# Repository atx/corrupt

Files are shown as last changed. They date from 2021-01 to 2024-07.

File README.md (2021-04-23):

# corrupt
A 65% keyboard with a somewhat non-standard layout. Inspired by the KBT Pure Pro.

corrupt

### Specs

 * Standard GH60-style case support
 * MX-style switches
 * 2U left shift (bottom row shifted by 0.25U to the left)
 * Standard 6.25U spacebar
 * USB-C (wired-only)
 * [zmk port](https://github.com/atx/zmk/tree/corrupt)
 * Compatible FR4 plate included in the repository
 * Under-the-spacebar WE-SKEDD debugging port
 * STM32F405 MCU (total overkill)
 * Both the key plate and the PCB can be manufactured by JLC, most components are available for PCBA

### Layout



### Debugging connector

skedd

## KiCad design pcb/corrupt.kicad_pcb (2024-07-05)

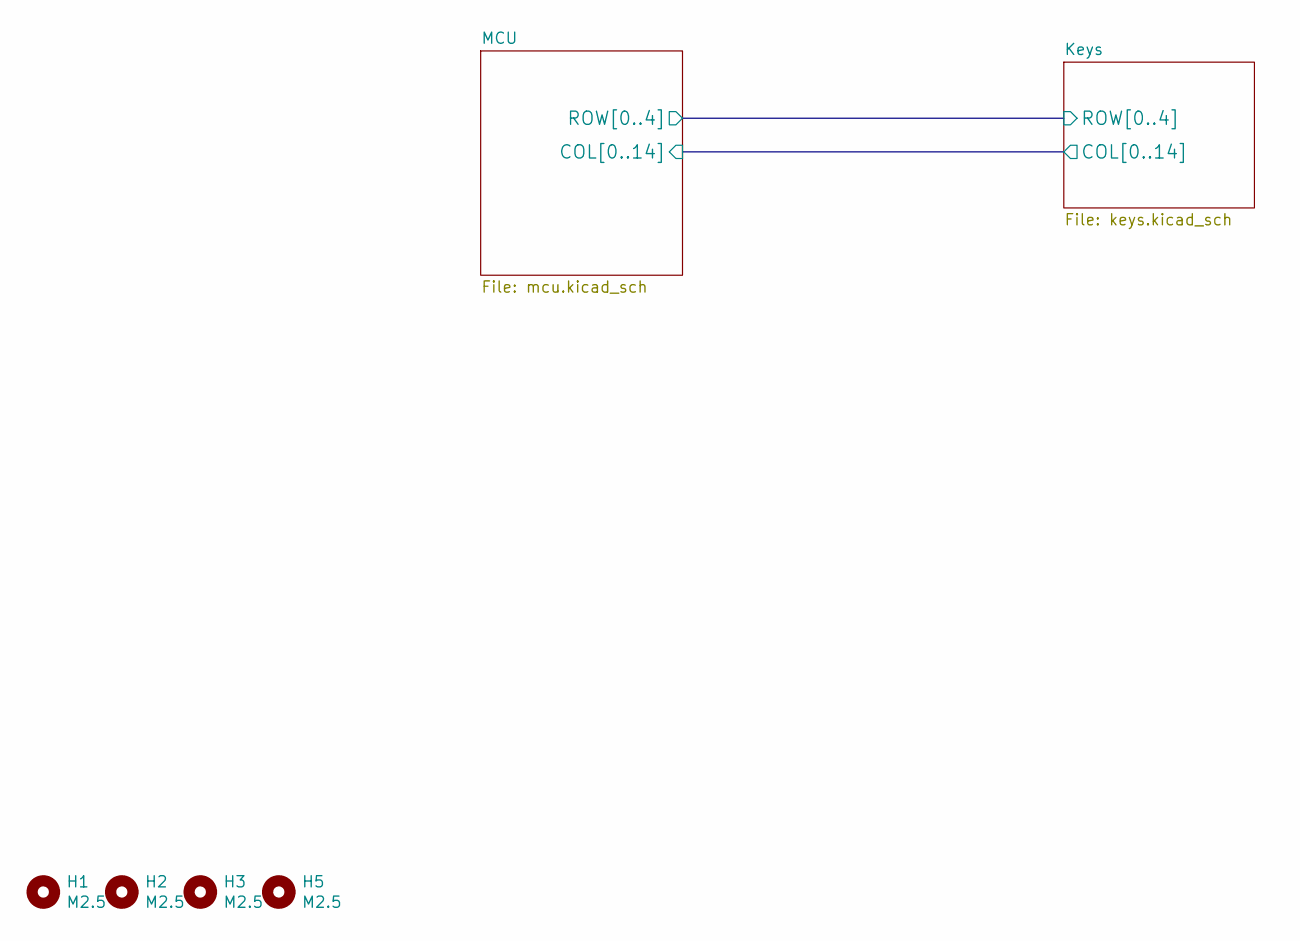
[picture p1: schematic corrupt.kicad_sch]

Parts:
H1, H2, H3, H5: M2.5; MountingHole_2.7mm_M2.5_Pad

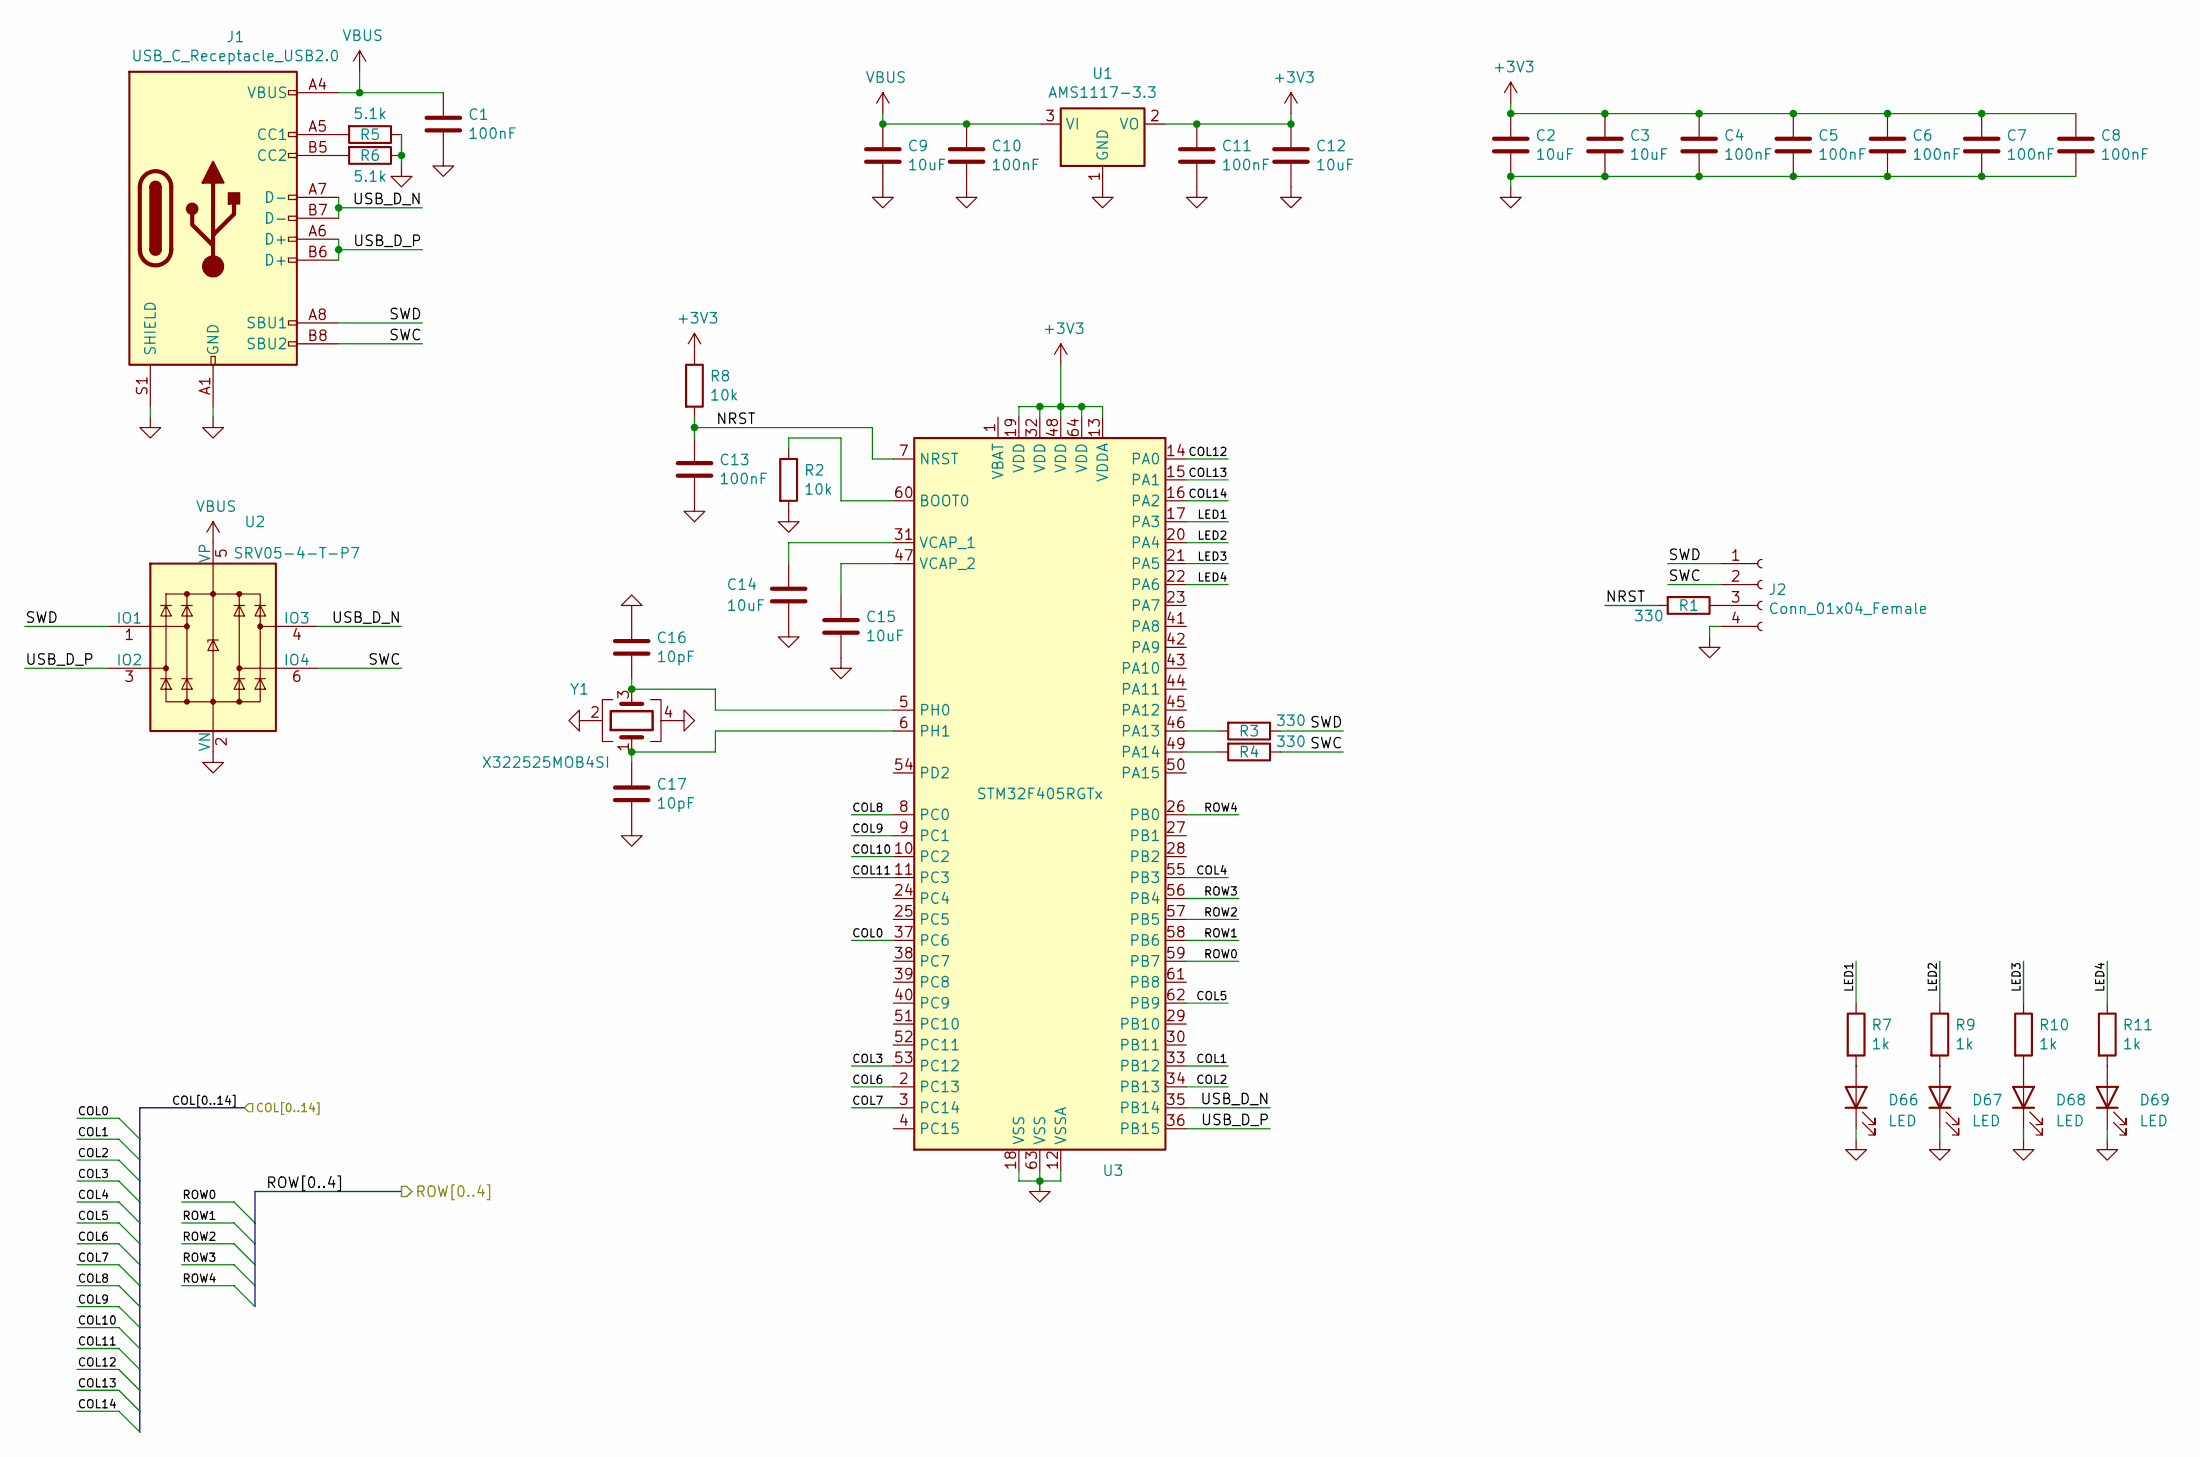
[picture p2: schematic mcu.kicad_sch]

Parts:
C1, C4, C5, C6, C7, C8, C10, C11, C13: 100nF; C_0402_1005Metric; LCSC C1525
C2, C3, C9, C12, C14, C15: 10uF; C_0603_1608Metric; LCSC C19702
C16, C17: 10pF; C_0402_1005Metric; LCSC C32949
D66, D67, D68, D69: LED; LED_0603_1608Metric
J1: USB_C_Receptacle_USB2.0; USB_C_Receptacle_Palconn_UTC16-G
J2: Conn_01x04_Female; WR-WST-4P-DBG
R1, R3, R4: 330; R_0402_1005Metric; LCSC C25104
R2, R8: 10k; R_0402_1005Metric; LCSC C25744
R5, R6: 5.1k; R_0402_1005Metric; LCSC C25905
R7, R9, R10, R11: 1k; R_0402_1005Metric; LCSC C11702
U1: AMS1117-3.3; SOT-223-3_TabPin2; LCSC C6186
U2: SRV05-4-T-P7; SOT-23-6; LCSC C7420376
U3: STM32F405RGTx; LQFP-64_10x10mm_P0.5mm; LCSC C15742
Y1: X322525MOB4SI; Crystal_SMD_3225-4Pin_3.2x2.5mm; LCSC C9006

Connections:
+3V3: C2.1, C3.1, C4.1, C5.1, C6.1, C7.1, C8.1, C11.1, C12.1, R8.1, U1.2 (VO), U3.13 (VDDA), U3.19 (VDD), U3.32 (VDD), U3.48 (VDD), U3.64 (VDD)
/Keys/COL0: U3.37 (PC6); also elsewhere on the board
/Keys/COL1: U3.33 (PB12); also elsewhere on the board
/Keys/COL2: U3.34 (PB13); also elsewhere on the board
/Keys/COL3: U3.53 (PC12); also elsewhere on the board
/Keys/COL4: U3.55 (PB3); also elsewhere on the board
/Keys/COL5: U3.62 (PB9); also elsewhere on the board
/Keys/COL6: U3.2 (PC13); also elsewhere on the board
/Keys/COL7: U3.3 (PC14); also elsewhere on the board
/Keys/COL8: U3.8 (PC0); also elsewhere on the board
/Keys/COL9: U3.9 (PC1); also elsewhere on the board
/Keys/COL10: U3.10 (PC2); also elsewhere on the board
/Keys/COL11: U3.11 (PC3); also elsewhere on the board
/Keys/COL12: U3.14 (PA0); also elsewhere on the board
/Keys/COL13: U3.15 (PA1); also elsewhere on the board
/Keys/COL14: U3.16 (PA2); also elsewhere on the board
/Keys/ROW0: U3.59 (PB7); also elsewhere on the board
/Keys/ROW1: U3.58 (PB6); also elsewhere on the board
/Keys/ROW2: U3.57 (PB5); also elsewhere on the board
/Keys/ROW3: U3.56 (PB4); also elsewhere on the board
/Keys/ROW4: U3.26 (PB0); also elsewhere on the board
/MCU/LED1: R7.1, U3.17 (PA3)
/MCU/LED2: R9.1, U3.20 (PA4)
/MCU/LED3: R10.1, U3.21 (PA5)
/MCU/LED4: R11.1, U3.22 (PA6)
/MCU/NRST: C13.1, R1.2, R8.2, U3.7 (NRST)
/MCU/SWC: J1.B8 (SBU2), J2.2, R4.1, U2.6 (IO4)
/MCU/SWD: J1.A8 (SBU1), J2.1, R3.1, U2.1 (IO1)
/MCU/USB_D_N: J1.A7 (D-), J1.B7 (D-), U2.4 (IO3), U3.35 (PB14)
/MCU/USB_D_P: J1.A6 (D+), J1.B6 (D+), U2.3 (IO2), U3.36 (PB15)
GND: C1.2, C2.2, C3.2, C4.2, C5.2, C6.2, C7.2, C8.2, C9.2, C10.2, C11.2, C12.2, C13.2, C14.2, C15.2, C16.1, C17.2, D66.1 (K), D67.1 (K), D68.1 (K), D69.1 (K), J1.A1 (GND), J1.A12 (GND), J1.B1 (GND), J1.B12 (GND), J1.S1 (SHIELD), J2.4, R2.2, R5.1, R6.1, U1.1 (GND), U2.2 (VN), U3.12 (VSSA), U3.18 (VSS), U3.63 (VSS), Y1.2, Y1.4
unnamed: D66.2 (A), R7.2
unnamed: D67.2 (A), R9.2
unnamed: D68.2 (A), R10.2
unnamed: D69.2 (A), R11.2
unnamed: J1.A5 (CC1), R5.2
unnamed: J1.B5 (CC2), R6.2
unnamed: J2.3, R1.1
unnamed: R2.1, U3.60 (BOOT0)
unnamed: R3.2, U3.46 (PA13)
unnamed: R4.2, U3.49 (PA14)
unnamed: C16.2, U3.5 (PH0), Y1.3
unnamed: C17.1, U3.6 (PH1), Y1.1
unnamed: C14.1, U3.31 (VCAP_1)
unnamed: C15.1, U3.47 (VCAP_2)
VBUS: C1.1, C9.1, C10.1, J1.A4 (VBUS), J1.A9 (VBUS), J1.B4 (VBUS), J1.B9 (VBUS), U1.3 (VI), U2.5 (VP)

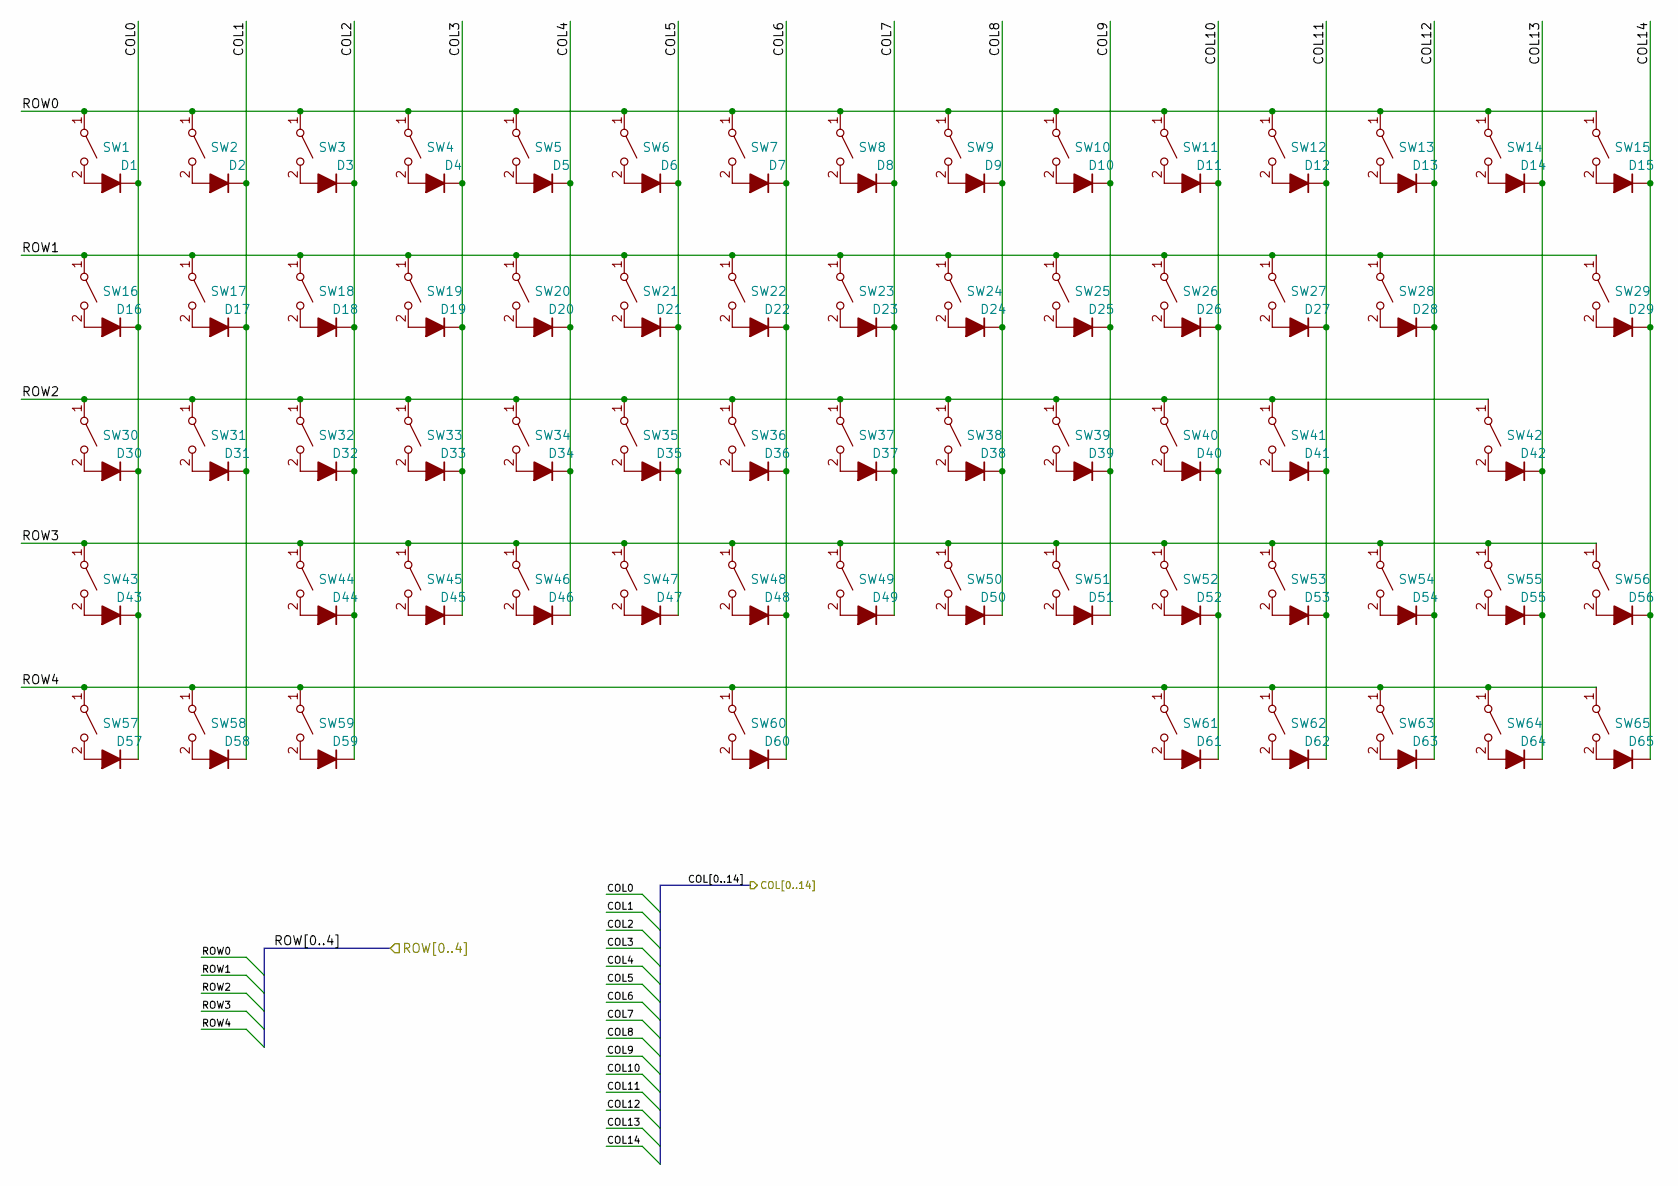
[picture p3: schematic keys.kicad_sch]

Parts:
D1, D2, D3, D4, D5, D6, D7, D8, D9, D10, D11, D12, D13, D14, D15, D16, D17, D18, D19, D20, D21, D22, D23, D24, D25, D26, D27, D28, D29, D30, D31, D32, D33, D34, D35, D36, D37, D38, D39, D40, D41, D42, D43, D44, D45, D46, D47, D48, D49, D50, D51, D52, D53, D54, D55, D56, D57, D58, D59, D60, D61, D62, D63, D64, D65: 1N4148WS; D_SOD-323; LCSC C2128
SW1, SW2, SW3, SW4, SW5, SW6, SW7, SW8, SW9, SW10, SW11, SW12, SW13, SW14, SW15, SW17, SW18, SW19, SW20, SW21, SW22, SW23, SW24, SW25, SW26, SW27, SW28, SW31, SW32, SW33, SW34, SW35, SW36, SW37, SW38, SW39, SW40, SW41, SW44, SW45, SW46, SW47, SW48, SW49, SW50, SW51, SW52, SW53, SW54, SW55, SW56, SW61, SW62, SW63, SW64, SW65: SW_SPST; SW_Cherry_MX_1.00u_PCB
SW16, SW29: SW_SPST; SW_Cherry_MX_1.50u_PCB
SW30: SW_SPST; SW_Cherry_MX_1.75u_PCB
SW42: SW_SPST; SW_Cherry_MX_2.25u_PCB
SW43: SW_SPST; SW_Cherry_MX_2.00u_PCB
SW57, SW58, SW59: SW_SPST; SW_Cherry_MX_1.25u_PCB
SW60: SW_SPST; SW_Cherry_MX_6.25u_PCB

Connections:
/Keys/COL0: D1.1 (K), D16.1 (K), D30.1 (K), D43.1 (K), D57.1 (K); also elsewhere on the board
/Keys/COL1: D2.1 (K), D17.1 (K), D31.1 (K), D58.1 (K); also elsewhere on the board
/Keys/COL2: D3.1 (K), D18.1 (K), D32.1 (K), D44.1 (K), D59.1 (K); also elsewhere on the board
/Keys/COL3: D4.1 (K), D19.1 (K), D33.1 (K), D45.1 (K); also elsewhere on the board
/Keys/COL4: D5.1 (K), D20.1 (K), D34.1 (K), D46.1 (K); also elsewhere on the board
/Keys/COL5: D6.1 (K), D21.1 (K), D35.1 (K), D47.1 (K); also elsewhere on the board
/Keys/COL6: D7.1 (K), D22.1 (K), D36.1 (K), D48.1 (K), D60.1 (K); also elsewhere on the board
/Keys/COL7: D8.1 (K), D23.1 (K), D37.1 (K), D49.1 (K); also elsewhere on the board
/Keys/COL8: D9.1 (K), D24.1 (K), D38.1 (K), D50.1 (K); also elsewhere on the board
/Keys/COL9: D10.1 (K), D25.1 (K), D39.1 (K), D51.1 (K); also elsewhere on the board
/Keys/COL10: D11.1 (K), D26.1 (K), D40.1 (K), D52.1 (K), D61.1 (K); also elsewhere on the board
/Keys/COL11: D12.1 (K), D27.1 (K), D41.1 (K), D53.1 (K), D62.1 (K); also elsewhere on the board
/Keys/COL12: D13.1 (K), D28.1 (K), D54.1 (K), D63.1 (K); also elsewhere on the board
/Keys/COL13: D14.1 (K), D42.1 (K), D55.1 (K), D64.1 (K); also elsewhere on the board
/Keys/COL14: D15.1 (K), D29.1 (K), D56.1 (K), D65.1 (K); also elsewhere on the board
/Keys/ROW0: SW1.1 (A), SW2.1 (A), SW3.1 (A), SW4.1 (A), SW5.1 (A), SW6.1 (A), SW7.1 (A), SW8.1 (A), SW9.1 (A), SW10.1 (A), SW11.1 (A), SW12.1 (A), SW13.1 (A), SW14.1 (A), SW15.1 (A); also elsewhere on the board
/Keys/ROW1: SW16.1 (A), SW17.1 (A), SW18.1 (A), SW19.1 (A), SW20.1 (A), SW21.1 (A), SW22.1 (A), SW23.1 (A), SW24.1 (A), SW25.1 (A), SW26.1 (A), SW27.1 (A), SW28.1 (A), SW29.1 (A); also elsewhere on the board
/Keys/ROW2: SW30.1 (A), SW31.1 (A), SW32.1 (A), SW33.1 (A), SW34.1 (A), SW35.1 (A), SW36.1 (A), SW37.1 (A), SW38.1 (A), SW39.1 (A), SW40.1 (A), SW41.1 (A), SW42.1 (A); also elsewhere on the board
/Keys/ROW3: SW43.1 (A), SW44.1 (A), SW45.1 (A), SW46.1 (A), SW47.1 (A), SW48.1 (A), SW49.1 (A), SW50.1 (A), SW51.1 (A), SW52.1 (A), SW53.1 (A), SW54.1 (A), SW55.1 (A), SW56.1 (A); also elsewhere on the board
/Keys/ROW4: SW57.1 (A), SW58.1 (A), SW59.1 (A), SW60.1 (A), SW61.1 (A), SW62.1 (A), SW63.1 (A), SW64.1 (A), SW65.1 (A); also elsewhere on the board
unnamed: D1.2 (A), SW1.2 (B)
unnamed: D2.2 (A), SW2.2 (B)
unnamed: D3.2 (A), SW3.2 (B)
unnamed: D4.2 (A), SW4.2 (B)
unnamed: D5.2 (A), SW5.2 (B)
unnamed: D6.2 (A), SW6.2 (B)
unnamed: D7.2 (A), SW7.2 (B)
unnamed: D8.2 (A), SW8.2 (B)
unnamed: D9.2 (A), SW9.2 (B)
unnamed: D10.2 (A), SW10.2 (B)
unnamed: D11.2 (A), SW11.2 (B)
unnamed: D12.2 (A), SW12.2 (B)
unnamed: D13.2 (A), SW13.2 (B)
unnamed: D14.2 (A), SW14.2 (B)
unnamed: D15.2 (A), SW15.2 (B)
unnamed: D16.2 (A), SW16.2 (B)
unnamed: D17.2 (A), SW17.2 (B)
unnamed: D18.2 (A), SW18.2 (B)
unnamed: D19.2 (A), SW19.2 (B)
unnamed: D20.2 (A), SW20.2 (B)
unnamed: D21.2 (A), SW21.2 (B)
unnamed: D22.2 (A), SW22.2 (B)
unnamed: D23.2 (A), SW23.2 (B)
unnamed: D24.2 (A), SW24.2 (B)
unnamed: D25.2 (A), SW25.2 (B)
unnamed: D26.2 (A), SW26.2 (B)
unnamed: D27.2 (A), SW27.2 (B)
unnamed: D28.2 (A), SW28.2 (B)
unnamed: D29.2 (A), SW29.2 (B)
unnamed: D30.2 (A), SW30.2 (B)
unnamed: D31.2 (A), SW31.2 (B)
unnamed: D32.2 (A), SW32.2 (B)
unnamed: D33.2 (A), SW33.2 (B)
unnamed: D34.2 (A), SW34.2 (B)
unnamed: D35.2 (A), SW35.2 (B)
unnamed: D36.2 (A), SW36.2 (B)
unnamed: D37.2 (A), SW37.2 (B)
unnamed: D38.2 (A), SW38.2 (B)
unnamed: D39.2 (A), SW39.2 (B)
unnamed: D40.2 (A), SW40.2 (B)
unnamed: D41.2 (A), SW41.2 (B)
unnamed: D42.2 (A), SW42.2 (B)
unnamed: D43.2 (A), SW43.2 (B)
unnamed: D44.2 (A), SW44.2 (B)
unnamed: D45.2 (A), SW45.2 (B)
unnamed: D46.2 (A), SW46.2 (B)
unnamed: D47.2 (A), SW47.2 (B)
unnamed: D48.2 (A), SW48.2 (B)
unnamed: D49.2 (A), SW49.2 (B)
unnamed: D50.2 (A), SW50.2 (B)
unnamed: D51.2 (A), SW51.2 (B)
unnamed: D52.2 (A), SW52.2 (B)
unnamed: D53.2 (A), SW53.2 (B)
unnamed: D54.2 (A), SW54.2 (B)
unnamed: D55.2 (A), SW55.2 (B)
unnamed: D56.2 (A), SW56.2 (B)
unnamed: D57.2 (A), SW57.2 (B)
unnamed: D58.2 (A), SW58.2 (B)
unnamed: D59.2 (A), SW59.2 (B)
unnamed: D60.2 (A), SW60.2 (B)
unnamed: D61.2 (A), SW61.2 (B)
unnamed: D62.2 (A), SW62.2 (B)
unnamed: D63.2 (A), SW63.2 (B)
unnamed: D64.2 (A), SW64.2 (B)
unnamed: D65.2 (A), SW65.2 (B)

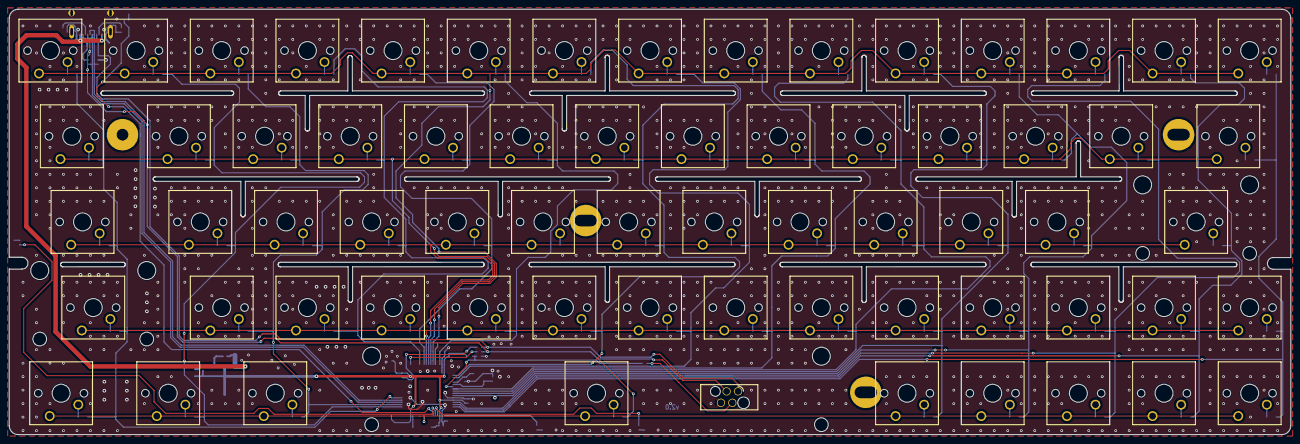
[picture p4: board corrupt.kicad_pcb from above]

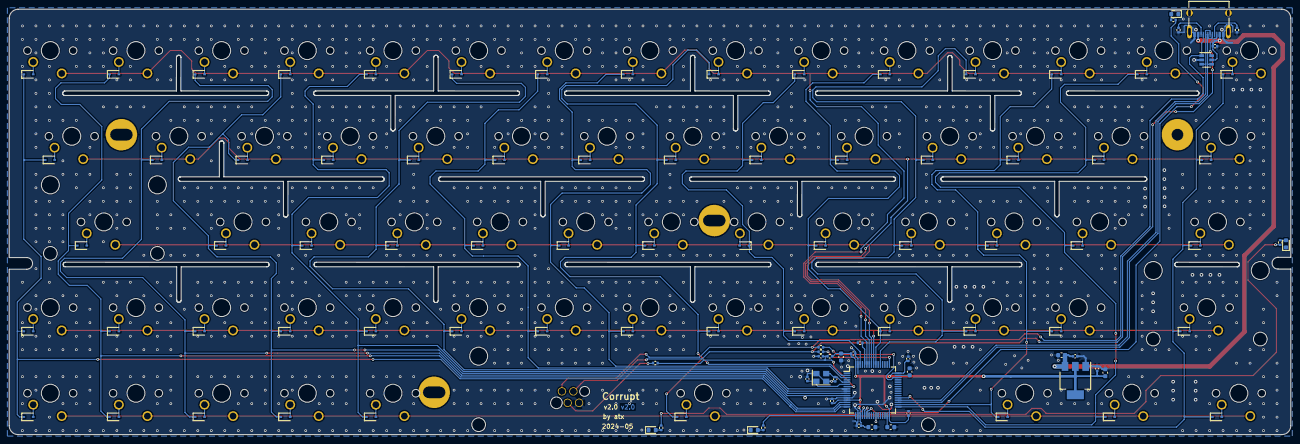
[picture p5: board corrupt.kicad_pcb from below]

Board: 2 copper layers, 285.0 x 94.6 mm, 172 parts (102 on the bottom side), 111 nets.

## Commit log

2021-01-30 pcb: v1.0
    Initial PCB version
    [corrupt.kicad_pcb, corrupt.sch, keys.sch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]
2024-07-05 Update to KiCad 8
    [corrupt.kicad_pcb, corrupt.kicad_sch, corrupt.sch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]
2024-07-05 pcb: v2.0
    [corrupt.kicad_pcb, keys.kicad_sch, mcu.kicad_sch]
